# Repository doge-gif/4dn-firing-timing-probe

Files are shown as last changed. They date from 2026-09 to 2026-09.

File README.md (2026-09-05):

# 4dn-firing-timing-probe

A Raspberry Pi Pico (RP2040) bench instrument that maps the ignition **advance
curve (°BTDC vs RPM)** of a Denso TNDF17 TCI ignitor (as fitted to the Yamaha
SRV250, renessa). It emulates the crankshaft pickup at a commanded RPM,
timestamps the resulting ignition-coil fire events, and writes the per-cylinder
timing to CSV files on an onboard FAT volume, retrieved over USB mass storage.

No engine required: the Pico is both the stimulus (a synthesized pickup pattern)
and the instrument (dual-edge capture + crank-angle reconstruction).

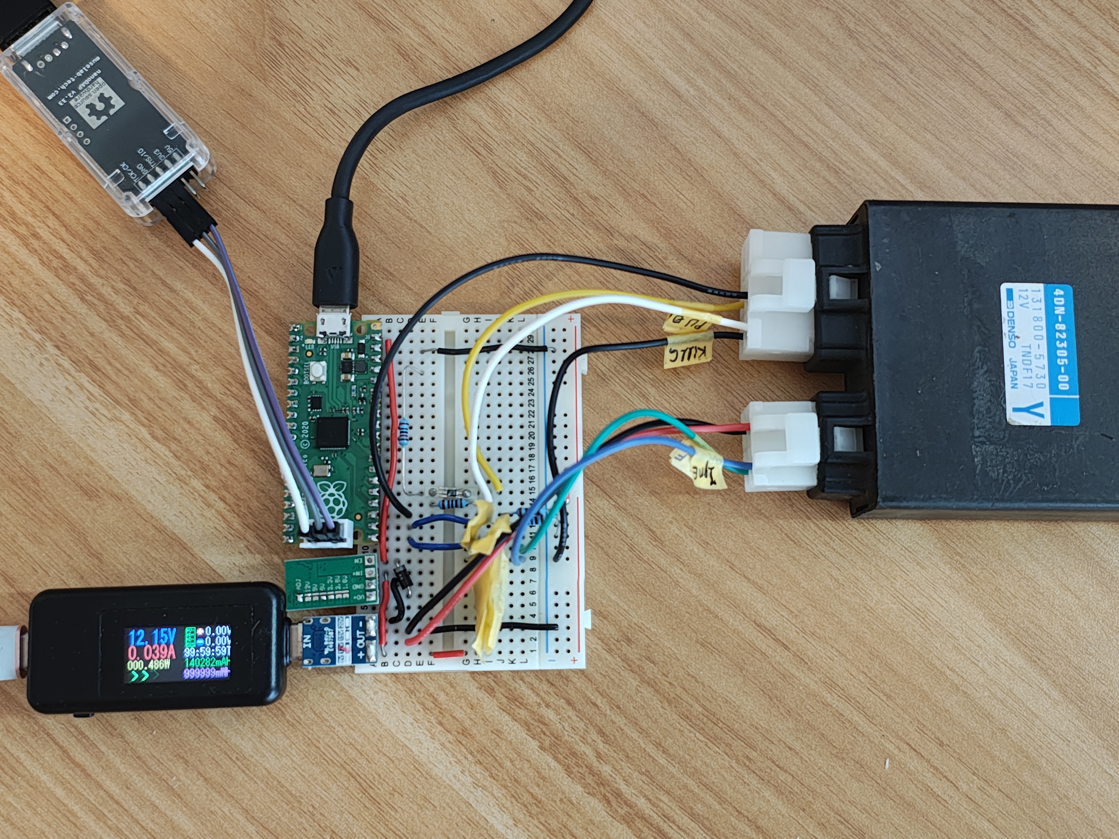
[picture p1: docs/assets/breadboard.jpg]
Breadboard prototype


> [!NOTE]
> This project is created with the help of AI. The schematic is made manually,
> but the firmware and documentation are generated with claude code.

## How it works

The Pico drives a synthesized VR/pickup pulse train on GP18 matching the SRV250
trigger wheel (4 teeth, 60/60/60/180°) at a commanded RPM. It captures both
edges of the ignitor's two coil outputs (GP16/GP17) and of its own emitted
pickup (GP18 self-capture) with the PIO on one shared 62.5 MHz timebase, then
computes each spark's °BTDC by interpolating its position between the bracketing
pickup edges relative to per-cylinder TDC. Details in
[docs/architecture.md](docs/architecture.md).

## Run modes & output

`RUN_MODE` in `CONFIG.INI` selects the run; results land as CSV on the USB drive:

| Mode | What it does | Output |
|---|---|---|
| `STEPPED` | Hold each RPM step, average N samples → advance map | `MAP_###.CSV` |
| `RAMP_UP` / `RAMP_DOWN` | Continuous RPM sweep, one row per spark | `RAMPU###.CSV` / `RAMPD###.CSV` |
| `HOLD` | Hold a constant RPM indefinitely, one row per spark | `HOLD###.CSV` |

## Quick start

1. **Flash the firmware.** Download the latest
   prober.uf2 from the project's GitHub [Releases][] page, then hold
   **BOOTSEL** while plugging in the Pico (it mounts as `RPI-RP2`) and copy the
   `.uf2` onto it. (Building from source instead:
   [docs/development.md](docs/development.md).)
2. **Wire the harness** to the ignitor — pin map in
   [docs/architecture.md](docs/architecture.md#hardware); board files and
   PCB/breadboard notes in [schematics/](schematics/README.md).
3. Mount the Pico's USB drive and edit `CONFIG.INI` — **run parameters only**;
   the wheel/TDC geometry is baked into the firmware.
4. **Reset** the Pico (config is read at boot), wait for the LED at 1 Hz
   (Ready), then press **BOOTSEL** to start the run.
5. Wait for the LED to return to steady **1 Hz (Ready)** — the run finished and
   the CSV is flushed — then replug the drive and copy the file. (Copying before
   the LED is Ready is too early; the file is written only at end-of-run.)

[Releases]: https://github.com/doge-gif/4dn-firing-timing-probe/releases/latest

## Repository layout

```
firmware/      C++20 firmware — core/ (SDK-free, host-tested), hal/, app/, tests/
schematics/    KiCad board + PCB/breadboard notes (schematics/README.md)
ci/            CI entry point (container build + lint + test)
docs/          architecture.md, development.md, refs/ (third-party sources)
results/       CSV output from my runs
flake.nix      Nix devShell (pinned toolchain: arm-none-eabi-gcc, probe-rs, …)
```

## License

Project source: see [LICENSE](LICENSE). Third-party reference materials indexed
in [docs/refs/SOURCES.md](docs/refs/SOURCES.md) remain under their own licenses.

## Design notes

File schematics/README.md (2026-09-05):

# 4DN Firing Timing Probe Schematics

This directory contains the schematics for the 4DN Firing Timing Probe.
See [releases][]: schematic.pdf for a PDF version.

The probe is simple enough that it'll work with a breadboard or protoboard. If
you want a proper PCB, use KiCad (10+) and send the gerbers to a fab house.

A gerber file for jlcpcb can be found in [releases][]: 4dn-firing-timing-probe-gerbers.zip.

[releases]: https://github.com/doge-gif/4dn-firing-timing-probe/releases/latest

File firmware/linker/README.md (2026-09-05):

# linker/

Link-time bound on the RAM-hot `.time_critical` code.

The `.time_critical` code is copied into the 264 KB SRAM at boot, so it is
capped at **12 KB** with a linker `ASSERT`: RAM-hot code that grows past the cap
is a BUILD FAILURE instead of silent RAM exhaustion at runtime.

## Files

- `prober_sections.ld` — extra `-T` fragment holding the top-level `ASSERT`
  (the 12 KB cap). Wired onto the `prober` target via `target_link_options` in
  `../src/CMakeLists.txt`.
- `section_default_data.incl` — override of the pico-sdk 2.3.0 file of the same
  name. Adds the `__time_critical_start__` / `__time_critical_end__` symbols
  that bracket `*(.time_critical*)`; the `ASSERT` asserts on their difference.
  Wired in via `pico_add_linker_script_override_path(prober ...)`.

## Why bracket symbols instead of `SIZEOF(.time_critical)`

In pico-sdk 2.x the `*(.time_critical*)` input sections are folded into the
`.data` output section (in SDK 1.x they were a standalone `.time_critical`
output section). So `SIZEOF(.time_critical)` is always 0 and a naive
`ASSERT(SIZEOF(.time_critical) <= 8K)` can never fire. Keeping the input inside
`.data` is also required for correctness: `crt0.S` copies
`[__data_start__, __data_end__)` from flash to SRAM at boot via a fixed copy
table, so relocating `.time_critical` into its own output section would leave
the hot functions uninitialised in RAM. Bracketing measures the code in place.

## Maintenance note

`section_default_data.incl` is a faithful copy of the vendored SDK file with
only the two bracket symbols added. If the vendored pico-sdk is bumped, re-sync
this override against the new `section_default_data.incl`.

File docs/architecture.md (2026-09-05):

# Architecture

How the prober turns a bare ignitor into an advance map, and how the firmware
and hardware are organised.

## Measurement principle

The SRV250 ignitor fires from a variable-reluctance crank pickup. The prober
*replaces the engine*: it synthesizes the pickup pulse train at a known,
commanded RPM and measures when the ignitor fires in response.

1. **Stimulus** — a CPU-timed pattern generator drives GP18 with the trigger
   wheel's edge sequence (4 teeth at 60/60/60/180°, each 10° wide) at the
   commanded RPM.
2. **Capture** — the PIO timestamps *both* edges of the two coil-drive outputs
   and of the emitted pickup itself, all against one free-running counter.
3. **Reconstruction** — each spark's crank angle is interpolated between the two
   pickup edges that bracket it; °BTDC = (TDC_ref − angle) mod wheel.

Because the pickup is emitted by the prober, the commanded RPM is exact and the
spark timing is measured, not assumed.

## Signal path and timebase

- **Pattern gen** (`hal/soft_pattern.hpp`): edges are emitted from a hardware
  timer-alarm IRQ, each edge time derived from the rev start plus a geometric
  fraction of the rev period — drift-free, and independent of main-loop load.
  RPM changes apply at the next rev boundary.
- **Capture** (`hal/capture.*`, `hal/capture.pio`): one PIO state machine per
  input pin does dual-edge timestamping into an SRAM ring via DMA, with the pin
  level packed into the timestamp so a dropped edge can't invert polarity. All
  SMs share clkdiv 1.0; the capture counter ticks at sysclk/2 = **62.5 MHz**
  (`kCaptureTicksPerCount = 2`). All capture SMs start in one synchronized batch, so
  they share a single phase-locked timebase.
- **Skew correction** (`core/skew.hpp`): each capture SM's counter pauses a
  fixed ~2.75 counts per edge it handles, so a fast channel (pickup, 8
  edges/rev) drifts against a slow one (a coil, ~2/rev). Each channel's
  accumulated pause is added back so all channels share one pause-free timebase
  — otherwise a spark compared to a tooth drifts over a run.

## BTDC computation

For each spark, `bracket_pk` finds the two emitted pickup edges `b`,`a` with
`b.t ≤ spark_t < a.t` and `interp_angle` interpolates the crank angle between
their known wheel angles. This is a **ratio within one revolution**, so the
capture counter's absolute rate cancels out — the result is robust to clock-rate
drift, and skew-corrected on top. `to_btdc` folds it against the cylinder's TDC.
The stepped and ramp/hold reducers share this exact math.

## Run modes

- **STEPPED** — the pattern runs continuously while the schedule steps RPM from
  `SWEEP_START_RPM` to `SWEEP_END_RPM` by `SWEEP_STEP_RPM`. At each step it lets
  the ignitor settle `SWEEP_SETTLE_REVS` revs, then averages `SWEEP_SAMPLES`
  sparks per cylinder (Welford mean/σ + median/min/max) into one row. An RPM
  with no fire is emitted as an `n=0` marker row (maps the cranking/redline
  edges). → `MAP_###.CSV`.
- **RAMP_UP / RAMP_DOWN** — RPM is integrated continuously by wall-clock time at
  `RAMP_UP_RPM_PER_S` / `RAMP_DOWN_RPM_PER_S` between the sweep bounds; every
  bracketable spark emits one raw row (no averaging). Hard-capped at 40 s.
  → `RAMPU###.CSV` / `RAMPD###.CSV`.
- **HOLD** — slews to `HOLD_RPM` and holds it indefinitely, one row per spark
  into a fixed most-recent-N window, until BOOTSEL is pressed. → `HOLD###.CSV`.

RAMP and HOLD share the per-spark reducer; STEPPED has its own averaging
reducer. All three share the pattern gen, capture, skew correction, and BTDC
math.

## Configuration model

Two tiers, deliberately split:

- **Baked geometry** (`firmware/src/constants.hpp`) — the DUT/wheel facts that
  are a property of the board, not an operator setting: `kWheelDeg`, the tooth
  spans, per-cylinder `kTdcRefDeg`, and the ignition-sense pins `kIgnPins`. The
  per-cylinder arrays are ordered in lockstep (cylinder *i* uses `kIgnPins[i]`
  and `kTdcRefDeg[i]`). Change these only for a different engine/board, then
  rebuild.
- **Run parameters** (`CONFIG.INI` on the USB volume) — `RUN_MODE`, the
  `SWEEP_*` scalars, optional `HOLD_RPM`, and the `RAMP_*_RPM_PER_S` rates. Read
  once at boot. A fresh device writes the baked default
  (`firmware/src/default_config.ini`, embedded via C23 `#embed`).

INI format: `key = value`; `;` starts a comment anywhere on a line; `:`
separates list items (e.g. per-cylinder values); keys are case-insensitive.

## Firmware structure

```
core/   Pure, SDK-free logic (INI parse, config validation, geometry, angle
        interpolation, skew, stats, CSV, FSM). Compiled for the host and unit-
        tested with doctest — no hardware needed.
hal/    RP2040 SDK layer: CPU pattern gen + PIO capture, DMA, GPIO, USB-MSC, flash
        FAT (FatFs). Isolated behind narrow interfaces.
app/    The application: dual-core wiring, run modes, the flush path.
```

**Dual-core split** (`app/`):

- **core0** (`main.cpp`) — USB (TinyUSB MSC), the tick-based FSM, and the
  end-of-run flush to flash. Owns all flash writes.
- **core1** (`core1_main.cpp`) — the deterministic domain: pattern emission,
  capture drain, per-spark reduction. Never touches flash during a run.

Rows cross core1→core0 over lock-free SPSC rings. Flash is written only at
end-of-run, while capture is idle and core1 is held in a RAM-resident lockout,
so an XIP flash program can't fault the other core.

**FSM states and LED** (`core/fsm.cpp`):

| State | LED | Meaning |
|---|-----|---|
| Ready | 1 Hz blink | idle; press BOOTSEL to start |
| Running | heartbeat | a run is in progress |
| Flush | double-blink | writing the CSV to flash |
| Done | brief solid | flush complete → returns to Ready |
| Error | triple-blink | lost sync (run aborted; no file written) |
| ConfigInvalid | 10 Hz blink | `CONFIG.INI` rejected at boot |

## Hardware

A Raspberry Pi Pico on a custom carrier PCB (KiCad project in
[`schematics/`](../schematics/README.md); it also runs on a breadboard).

The ignitor's internal output behaviour that the sense wiring and capture polarity
depend on — idle-high coil-drive outputs (12 V pull-up, pulled low during dwell) and
an open-collector tach — is derived from a
[reverse-engineered TNDF17 schematic](https://github.com/doge-gif/denso-TNDF17-reverse-engineer/blob/master/original_denso_TNDF17.pdf).

- **Power** — external 12 V (from a USB-C PD trigger negotiated by a CH221K)
  feeds the ignitor and an LM7805 12 V→5 V regulator; the 5 V drives Pico VSYS
  through a Schottky, source-OR'd with USB VBUS so the board runs standalone or
  over USB.
- **Pickup output** — GP18 → 100 Ω series resistor → the ignitor's pickup input;
  the 3V3 edge is enough to trigger its input stage.
- **Ignition sense (×2)** — each coil-drive line has a strong ≈470 Ω pull-up to
  +12 V, then a 2.7 kΩ / 1 kΩ divider scales the node down to just under 3.3 V at the
  MCU pin. Non-inverting, so the ignitor's collector polarity is preserved:
  idle-high, dwell-low, **spark = rising edge** — matching the firmware's idle-high
  capture.
- **Tach input (optional)** — GP19 via a low-Vf Schottky + 10 kΩ pull-up to 3V3;
  the ignitor's tach is an open-collector node, present only with a real ignitor.
- **Kill switch** — CONN_G pulled up; leave it open for run-enabled.

**Pin map:**

| GPIO | Signal | Notes |
|---|---|---|
| GP16 | Ignition sense, cylinder 2 | CONN_E |
| GP17 | Ignition sense, cylinder 1 | CONN_F |
| GP18 | Pickup output | SIO-driven; also PIO self-captured |
| GP19 | Tach input (optional) | reference diagnostic; absent on the bench |
| GP25 | Status LED | onboard |
| BOOTSEL | Start button | read via the QSPI-CS technique |

Note the cylinder↔connector mapping: CONN_E is cylinder 2 (GP16) and CONN_F is
cylinder 1 (GP17), so `kIgnPins = {17, 16}` (cyl0, cyl1).

## Output CSV formats

- **Stepped** (`MAP_###.CSV`):
  `rpm_cmd,cyl,n,mean_btdc_deg,median_btdc_deg,stddev_btdc_deg,min_btdc_deg,max_btdc_deg,mean_dwell_us,stddev_dwell_us,mean_sys_latency_us,tach_rpm`
- **Ramp / Hold** (`RAMPU###.CSV`, `RAMPD###.CSV`, `HOLD###.CSV`):
  `rpm_cmd,cyl,rev_period_us,btdc_deg,dwell_us`

Files are never overwritten — the firmware scans the volume for the lowest free
`###` on each flush.

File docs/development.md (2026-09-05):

# Development

Build, test, flash, and debug. Firmware structure and hardware are in
[architecture.md](architecture.md).

## Getting the source

The submodule dependencies are all top-level (`pico-sdk`, `doctest`, and
`tinyusb` — vendored directly rather than through pico-sdk's nested
`lib/tinyusb`, so no recursive fetch is needed). They are marked
`shallow = true`, so a single non-recursive init clones depth-1 snapshots only
(≈60 MB of `.git` instead of ≈470 MB); pico-sdk's unused nested libraries
(btstack, mbedtls, …) are never fetched. The checked-out files are identical.
(FatFs is not a submodule — it is vendored in-tree under `firmware/external/fatfs`
and needs no fetch; see [firmware/external/README.md](../firmware/external/README.md).)

```sh
git clone https://…/4dn-firing-timing-probe.git
# already cloned:
git submodule update --init
```

Two things when bumping the pico-sdk pin: re-pin `external/tinyusb` to the
tinyusb commit the new SDK expects (see `.gitmodules`), and fetch depth-matched
since shallow submodules lack other commits' history:
`git submodule update --remote --depth 1`.

## Toolchain

Everything runs inside one of two pinned environments — don't rely on host
tools:

- **Nix devShell** (local, recommended): `nix develop`. Provides
  `arm-none-eabi-gcc`, `cmake`, `probe-rs`, and the linters. Commands below
  assume you are inside it.
  Follow <https://nixos.org/download> to install Nix package manager.
- **Container** (what CI uses): `firmware/docker/run.sh bash -lc '…'`, built
  from the pinned image in `firmware/docker/`.

## Host unit tests

`core/` is SDK-free and tested with doctest on the host — no hardware:

```sh
cmake -S firmware -B build-host -DBUILD_TARGET=host
cmake --build build-host -j
ctest --test-dir build-host --output-on-failure
```

This is the default development path; run it before every commit.

## Firmware build

```sh
export PICO_SDK_PATH="$PWD/firmware/external/pico-sdk"
cmake -S firmware -B build-pico -DBUILD_TARGET=pico -DPICO_BOARD=pico
cmake --build build-pico --target prober -j
```

Outputs land in `build-pico/src/`: `prober.uf2` (for BOOTSEL/UF2) and
`prober.elf` (for probe-rs). Add `-DPROBER_HILTEST=ON` to also build the
on-silicon HIL self-test firmwares (`hil_ignitor`, `hil_ramp`, …); the normal
`prober` build does not need it.

## Flash

**UF2 (no probe):** hold BOOTSEL while plugging in the Pico → it mounts as
`RPI-RP2` → copy `build-pico/src/prober.uf2` onto it.

**SWD via probe-rs (CMSIS-DAP / DAPLINK):**

```sh
probe-rs download --chip RP2040 build-pico/src/prober.elf
probe-rs reset --chip RP2040
```

`download` reprograms only the firmware region — it does **not** touch the
top-of-flash FAT volume, so `CONFIG.INI` and result CSVs survive a reflash.

## Run and retrieve

1. Mount the Pico's USB drive; edit `CONFIG.INI` (run parameters only — see
   [architecture.md](architecture.md#configuration-model)).
2. **Reset** the Pico (config is read once at boot). LED patterns:

   | LED | State |
   |-----|-------|
   | 1 Hz blink | Ready — press BOOTSEL to start |
   | heartbeat | Running |
   | double-blink | Flushing the CSV |
   | brief solid | Done |
   | triple-blink | Error (lost sync; no file written) |
   | 10 Hz blink | Config invalid (fix `CONFIG.INI`) |

3. Press **BOOTSEL** to start. The volume is writer-locked read-only during a
   run.
4. **Wait for steady 1 Hz (Ready)** — the file is written only at end-of-run
   flush. Then replug the drive (the auto media-change is not reliable on all
   hosts) and copy the CSV.

## Debugging

- **SWD perturbs the pickup.** Poking RAM / halting over SWD during a *live
  run* garbles emission and measurement (and can even trip a USB panic). Read
  markers only when idle/Ready; for live signal checks use a scope on GP18 and
  the spark lines, not SWD.
- **Hung board:** `probe-rs gdb --chip RP2040 …` then attach `arm-none-eabi-gdb`
  (thread 1 = core0, thread 2 = core1) to read the fault PC / backtrace. Give
  the stub a few seconds to come up.
- **Corrupt FS recovery:** zero the FAT boot sector to force a reformat on next
  boot (the device rewrites a default `CONFIG.INI`):

  ```sh
  head -c 4096 /dev/zero > zero4k.bin
  probe-rs download --chip RP2040 --binary-format bin --base-address 0x10180000 zero4k.bin
  probe-rs reset --chip RP2040
  ```

  (`probe-rs erase` full-chip is unreliable on the DAPLINK; zeroing the boot
  sector is the working path.)

## Full CI locally

Build + lint (rumdl/shfmt/shellcheck/hadolint) + host & pico builds +
clang-format + clang-tidy, exactly as CI runs it:

```sh
firmware/docker/run.sh bash -lc '../ci/run.sh'
```

## Commit hooks

`lefthook` runs `clang-format`, `gersemi`, `rumdl`, `shfmt`, and `shellcheck` on
commit — **commit from inside `nix develop`** so the hooks are on PATH.
`clang-format` frequently reformats and fails the first attempt; the reliable
pattern is `clang-format -i <files>` → `git add` → `git commit`.

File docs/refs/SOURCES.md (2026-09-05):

# Reference Sources

Third-party documents mirrored in this directory for offline development.
Each file is covered by its original author's license.

| File | Origin URL | Retrieved | License |
|---|---|---|---|
| rp2040-datasheet.pdf | https://datasheets.raspberrypi.com/rp2040/rp2040-datasheet.pdf | 2026-09-04 | © Raspberry Pi Ltd |
| pico-datasheet.pdf | https://datasheets.raspberrypi.com/pico/pico-datasheet.pdf | 2026-09-04 | © Raspberry Pi Ltd |
| hardware-design-with-rp2040.pdf | https://datasheets.raspberrypi.com/rp2040/hardware-design-with-rp2040.pdf | 2026-09-04 | © Raspberry Pi Ltd |
| raspberry-pi-pico-c-sdk.pdf | https://datasheets.raspberrypi.com/pico/raspberry-pi-pico-c-sdk.pdf | 2026-09-04 | BSD-3-Clause |
| getting-started-with-pico.pdf | https://datasheets.raspberrypi.com/pico/getting-started-with-pico.pdf | 2026-09-04 | © Raspberry Pi Ltd |

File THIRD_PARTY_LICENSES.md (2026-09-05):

# Third-Party Licenses

<!-- GENERATED FILE — do not edit by hand.
     Regenerate with: scripts/gen-third-party-licenses.sh
     Source of truth: THIRD_PARTY_MANIFEST.tsv -->

This project bundles the third-party components below. Each is distributed under
its own license, reproduced verbatim here. Ship this file alongside the firmware
binary (prober.uf2) to satisfy those licenses' attribution requirements.

## Components in the firmware binary (prober.uf2)

### Raspberry Pi Pico SDK — BSD-3-Clause

```text
Copyright 2020 (c) 2020 Raspberry Pi (Trading) Ltd.

Redistribution and use in source and binary forms, with or without modification, are permitted provided that the
following conditions are met:

1. Redistributions of source code must retain the above copyright notice, this list of conditions and the following
   disclaimer.

2. Redistributions in binary form must reproduce the above copyright notice, this list of conditions and the following
   disclaimer in the documentation and/or other materials provided with the distribution.

3. Neither the name of the copyright holder nor the names of its contributors may be used to endorse or promote products
   derived from this software without specific prior written permission.

THIS SOFTWARE IS PROVIDED BY THE COPYRIGHT HOLDERS AND CONTRIBUTORS "AS IS" AND ANY EXPRESS OR IMPLIED WARRANTIES,
INCLUDING, BUT NOT LIMITED TO, THE IMPLIED WARRANTIES OF MERCHANTABILITY AND FITNESS FOR A PARTICULAR PURPOSE ARE
DISCLAIMED. IN NO EVENT SHALL THE COPYRIGHT HOLDER OR CONTRIBUTORS BE LIABLE FOR ANY DIRECT, INDIRECT, INCIDENTAL,
SPECIAL, EXEMPLARY, OR CONSEQUENTIAL DAMAGES (INCLUDING, BUT NOT LIMITED TO, PROCUREMENT OF SUBSTITUTE GOODS OR
SERVICES; LOSS OF USE, DATA, OR PROFITS; OR BUSINESS INTERRUPTION) HOWEVER CAUSED AND ON ANY THEORY OF LIABILITY,
WHETHER IN CONTRACT, STRICT LIABILITY, OR TORT (INCLUDING NEGLIGENCE OR OTHERWISE) ARISING IN ANY WAY OUT OF THE USE OF
THIS SOFTWARE, EVEN IF ADVISED OF THE POSSIBILITY OF SUCH DAMAGE.
```

### TinyUSB — MIT

```text
The MIT License (MIT)

Copyright (c) 2018, hathach (tinyusb.org)

Permission is hereby granted, free of charge, to any person obtaining a copy
of this software and associated documentation files (the "Software"), to deal
in the Software without restriction, including without limitation the rights
to use, copy, modify, merge, publish, distribute, sublicense, and/or sell
copies of the Software, and to permit persons to whom the Software is
furnished to do so, subject to the following conditions:

The above copyright notice and this permission notice shall be included in
all copies or substantial portions of the Software.

THE SOFTWARE IS PROVIDED "AS IS", WITHOUT WARRANTY OF ANY KIND, EXPRESS OR
IMPLIED, INCLUDING BUT NOT LIMITED TO THE WARRANTIES OF MERCHANTABILITY,
FITNESS FOR A PARTICULAR PURPOSE AND NONINFRINGEMENT. IN NO EVENT SHALL THE
AUTHORS OR COPYRIGHT HOLDERS BE LIABLE FOR ANY CLAIM, DAMAGES OR OTHER
LIABILITY, WHETHER IN AN ACTION OF CONTRACT, TORT OR OTHERWISE, ARISING FROM,
OUT OF OR IN CONNECTION WITH THE SOFTWARE OR THE USE OR OTHER DEALINGS IN
THE SOFTWARE.
```

### FatFs (ELM ChaN) — BSD-1-Clause

**Provenance:** Vendored from http://elm-chan.org/fsw/ff/ (R0.15a, retrieved 2026-09-02)

```text
FatFs License

FatFs has being developped as a personal project of the author, ChaN. It is free from the code anyone else wrote at current release. Following code block shows a copy of the FatFs license document that heading the source files.

/*----------------------------------------------------------------------------/
/  FatFs - Generic FAT Filesystem Module  Rx.xx                               /
/-----------------------------------------------------------------------------/
/
/ Copyright (C) 20xx, ChaN, all right reserved.
/
/ FatFs module is an open source software. Redistribution and use of FatFs in
/ source and binary forms, with or without modification, are permitted provided
/ that the following condition is met:
/
/ 1. Redistributions of source code must retain the above copyright notice,
/    this condition and the following disclaimer.
/
/ This software is provided by the copyright holder and contributors "AS IS"
/ and any warranties related to this software are DISCLAIMED.
/ The copyright owner or contributors be NOT LIABLE for any damages caused
/ by use of this software.
/----------------------------------------------------------------------------*/

Therefore FatFs license is one of the BSD-style licenses, but there is a significant feature. FatFs is mainly intended for embedded systems. In order to extend the usability for commercial products, the redistributions of FatFs in binary form, such as embedded code, binary library and any forms without source code, do not need to include about FatFs in the documentations. This is equivalent to the 1-clause BSD license. Of course FatFs is compatible with the most of open source software licenses include GNU GPL. When you redistribute the FatFs source code with changes or create a fork, the license can also be changed to GNU GPL, BSD-style license or any open source software license that not conflict with FatFs license.
```

## Components used only for host tests (not in prober.uf2)

The following are build/test dependencies only. They are not linked into the
distributed firmware, and are listed here for completeness.

### doctest — MIT

```text
The MIT License (MIT)

Copyright (c) 2016-2023 Viktor Kirilov

Permission is hereby granted, free of charge, to any person obtaining a copy
of this software and associated documentation files (the "Software"), to deal
in the Software without restriction, including without limitation the rights
to use, copy, modify, merge, publish, distribute, sublicense, and/or sell
copies of the Software, and to permit persons to whom the Software is
furnished to do so, subject to the following conditions:

The above copyright notice and this permission notice shall be included in all
copies or substantial portions of the Software.

THE SOFTWARE IS PROVIDED "AS IS", WITHOUT WARRANTY OF ANY KIND, EXPRESS OR
IMPLIED, INCLUDING BUT NOT LIMITED TO THE WARRANTIES OF MERCHANTABILITY,
FITNESS FOR A PARTICULAR PURPOSE AND NONINFRINGEMENT. IN NO EVENT SHALL THE
AUTHORS OR COPYRIGHT HOLDERS BE LIABLE FOR ANY CLAIM, DAMAGES OR OTHER
LIABILITY, WHETHER IN AN ACTION OF CONTRACT, TORT OR OTHERWISE, ARISING FROM,
OUT OF OR IN CONNECTION WITH THE SOFTWARE OR THE USE OR OTHER DEALINGS IN THE
SOFTWARE.
```

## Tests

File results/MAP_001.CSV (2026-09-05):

# firmware: v1.0.1
rpm_cmd | cyl | n | mean_btdc_deg | median_btdc_deg | stddev_btdc_deg | min_btdc_deg | max_btdc_deg | mean_dwell_us | stddev_dwell_us | mean_sys_latency_us | tach_rpm
100 | 0 | 16 | 9.83 | 9.83 | 0.00 | 9.83 | 9.83 | 100145.05 | 1.10 | 200.02 | 100.00
100 | 1 | 16 | 9.83 | 9.83 | 0.00 | 9.83 | 9.83 | 100135.58 | 0.81 | 200.02 | 100.00
200 | 0 | 16 | 9.66 | 9.66 | 0.00 | 9.65 | 9.66 | 50145.00 | 1.91 | 200.27 | 191.30
200 | 1 | 16 | 9.67 | 9.67 | 0.00 | 9.66 | 9.67 | 50136.07 | 2.50 | 200.27 | 191.30
300 | 0 | 16 | 9.48 | 9.48 | 0.00 | 9.47 | 9.49 | 33479.22 | 5.93 | 200.06 | 293.33
300 | 1 | 16 | 9.50 | 9.50 | 0.00 | 9.50 | 9.50 | 33466.81 | 2.44 | 200.06 | 293.33
400 | 0 | 16 | 9.32 | 9.33 | 0.00 | 9.31 | 9.33 | 25144.87 | 3.27 | 200.20 | 394.03
400 | 1 | 16 | 9.35 | 9.35 | 0.00 | 9.34 | 9.35 | 25135.20 | 2.53 | 200.20 | 394.03
500 | 0 | 16 | 9.16 | 9.16 | 0.01 | 9.13 | 9.16 | 20145.49 | 2.03 | 200.26 | 494.38
500 | 1 | 16 | 9.18 | 9.18 | 0.01 | 9.17 | 9.19 | 20135.32 | 3.26 | 200.26 | 494.38
600 | 0 | 16 | 8.99 | 8.99 | 0.00 | 8.98 | 8.99 | 16810.36 | 1.58 | 200.10 | 594.59
600 | 1 | 16 | 9.02 | 9.02 | 0.00 | 9.01 | 9.02 | 16802.99 | 1.15 | 200.10 | 594.59
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

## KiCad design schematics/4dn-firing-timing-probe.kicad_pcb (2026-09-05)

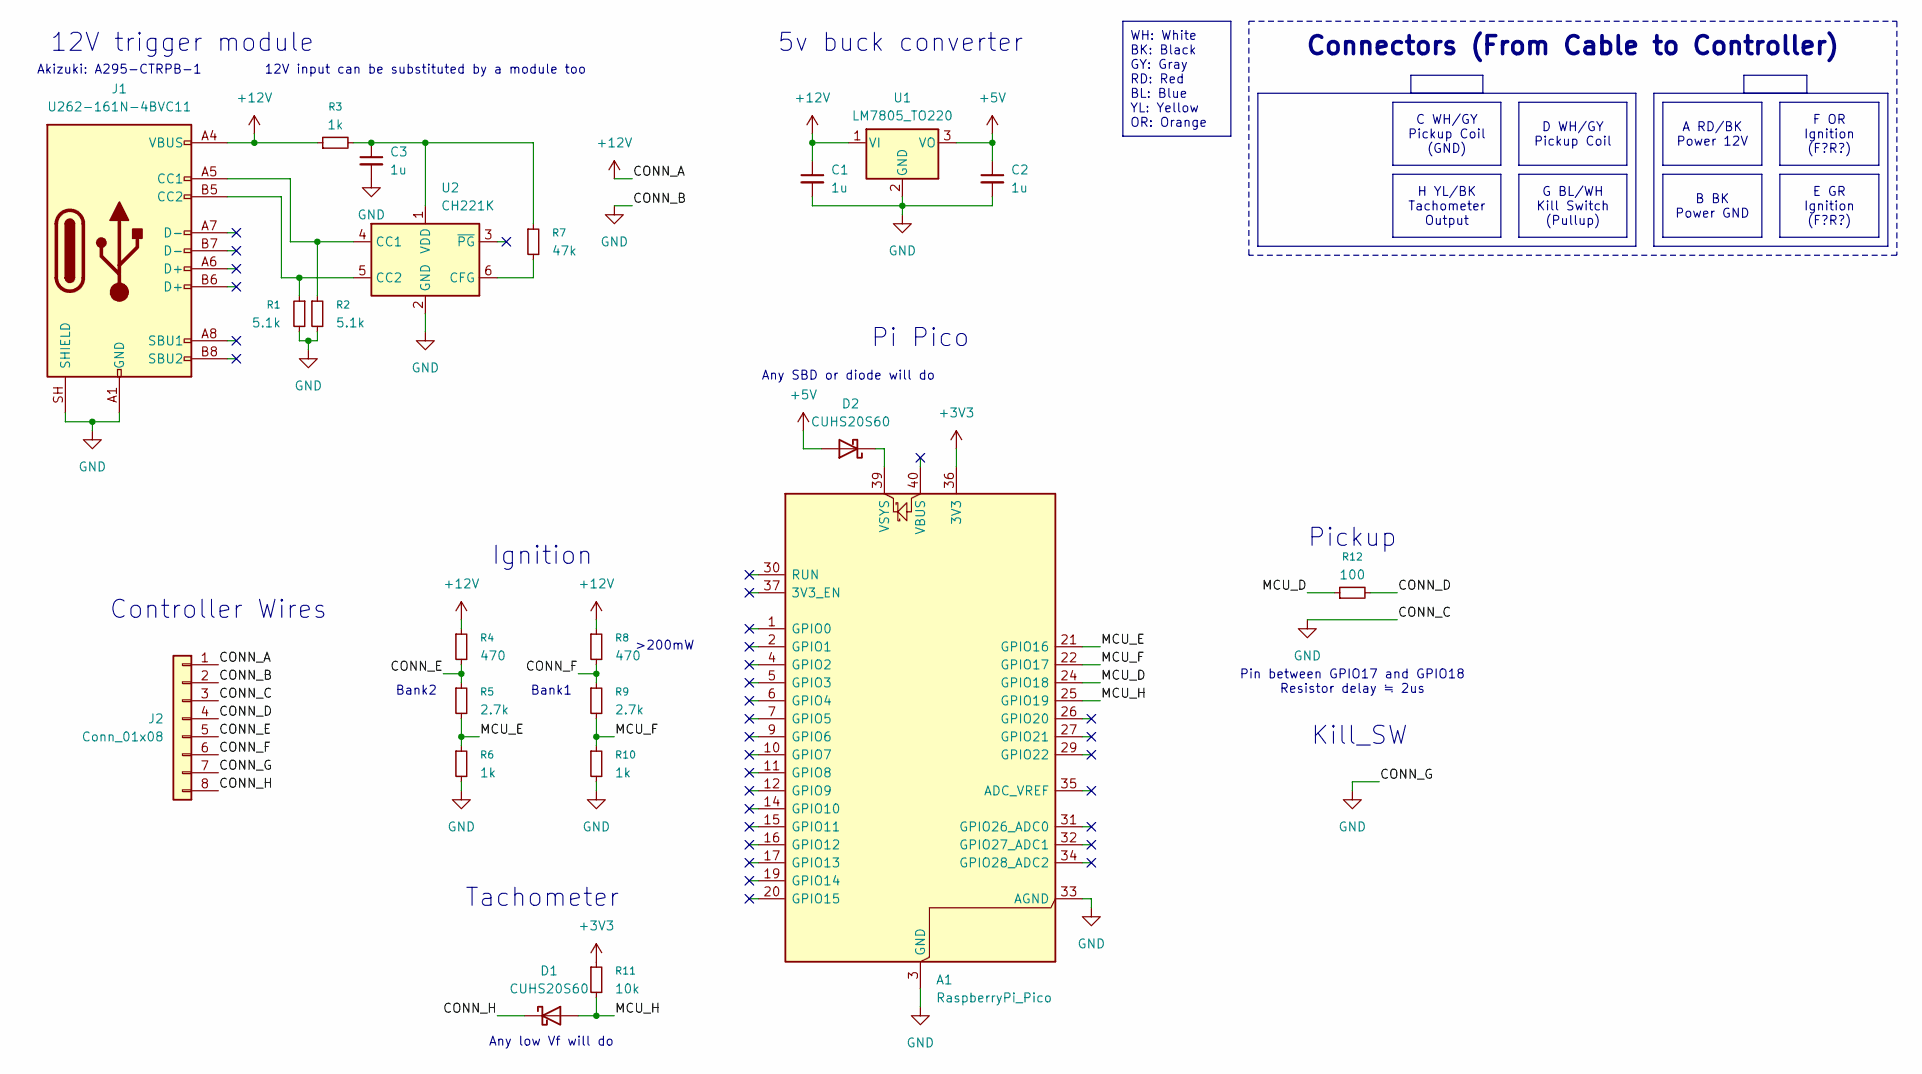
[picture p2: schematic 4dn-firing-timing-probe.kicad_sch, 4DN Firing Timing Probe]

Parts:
A1: RaspberryPi_Pico; RaspberryPi_Pico_Common_SMD
C1, C2, C3: 1u; C_0603_1608Metric
D1, D2: CUHS20S60; D_TUMD2
J1: U262-161N-4BVC11; USB_C_Receptacle_Palconn_UTC16-G
J2: Conn_01x08; PinHeader_1x08_P2.54mm_Vertical
R1, R2: 5.1k; R_0603_1608Metric
R3, R6, R10: 1k; R_0603_1608Metric
R4, R8: 470; R_1206_3216Metric
R5, R9: 2.7k; R_0603_1608Metric
R7: 47k; R_0603_1608Metric
R11: 10k; R_0603_1608Metric
R12: 100; R_0603_1608Metric
U1: LM7805_TO220; TO-220-3_Vertical
U2: CH221K; SOT-23-6

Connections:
+3V3: A1.36 (3V3), R11.1
+5V: C2.1, D2.2 (A), U1.3 (VO)
+12V: C1.1, J1.A4 (VBUS), J1.A9 (VBUS), J1.B4 (VBUS), J1.B9 (VBUS), J2.1, R3.1, R4.1, R8.1, U1.1 (VI)
/CONN_D: J2.4, R12.2
/CONN_E: J2.5, R4.2, R5.1
/CONN_F: J2.6, R8.2, R9.1
/CONN_H: D1.1 (K), J2.8
/MCU_D: A1.24 (GPIO18), R12.1
/MCU_E: A1.21 (GPIO16), R5.2, R6.1
/MCU_F: A1.22 (GPIO17), R9.2, R10.1
/MCU_H: A1.25 (GPIO19), D1.2 (A), R11.2
GND: A1.3 (GND), A1.8 (GND), A1.13 (GND), A1.18 (GND), A1.23 (GND), A1.28 (GND), A1.33 (AGND), A1.38 (GND), C1.2, C2.2, C3.2, J1.A1 (GND), J1.A12 (GND), J1.B1 (GND), J1.B12 (GND), J1.SH (SHIELD), J2.2, J2.3, J2.7, R1.2, R2.2, R6.2, R10.2, U1.2 (GND), U2.2 (GND)
unnamed: A1.39 (VSYS), D2.1 (K)
unnamed: J1.A5 (CC1), R2.1, U2.4 (CC1)
unnamed: J1.B5 (CC2), R1.1, U2.5 (CC2)
unnamed: R7.2, U2.6 (CFG)
unnamed: C3.1, R3.2, R7.1, U2.1 (VDD)

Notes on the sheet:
Bank2
Ignition
Tachometer
Akizuki: A295-CTRPB-1
Controller Wires
Pi Pico
Any low Vf will do
Any SBD or diode will do
Pickup
5v buck converter
Kill_SW
>200mW
Bank1
12V input can be substituted by a module too
12V trigger module
Pin between GPIO17 and GPIO18 Resistor delay ≒ 2us
A RD/BK Power 12V
G BL/WH Kill Switch (Pullup)
C WH/GY Pickup Coil (GND)
E GR Ignition (F?R?)
Connectors (From Cable to Controller)
B BK Power GND
D WH/GY Pickup Coil
WH: White BK: Black GY: Gray RD: Red BL: Blue YL: Yellow OR: Orange
F OR Ignition (F?R?)
H YL/BK Tachometer Output

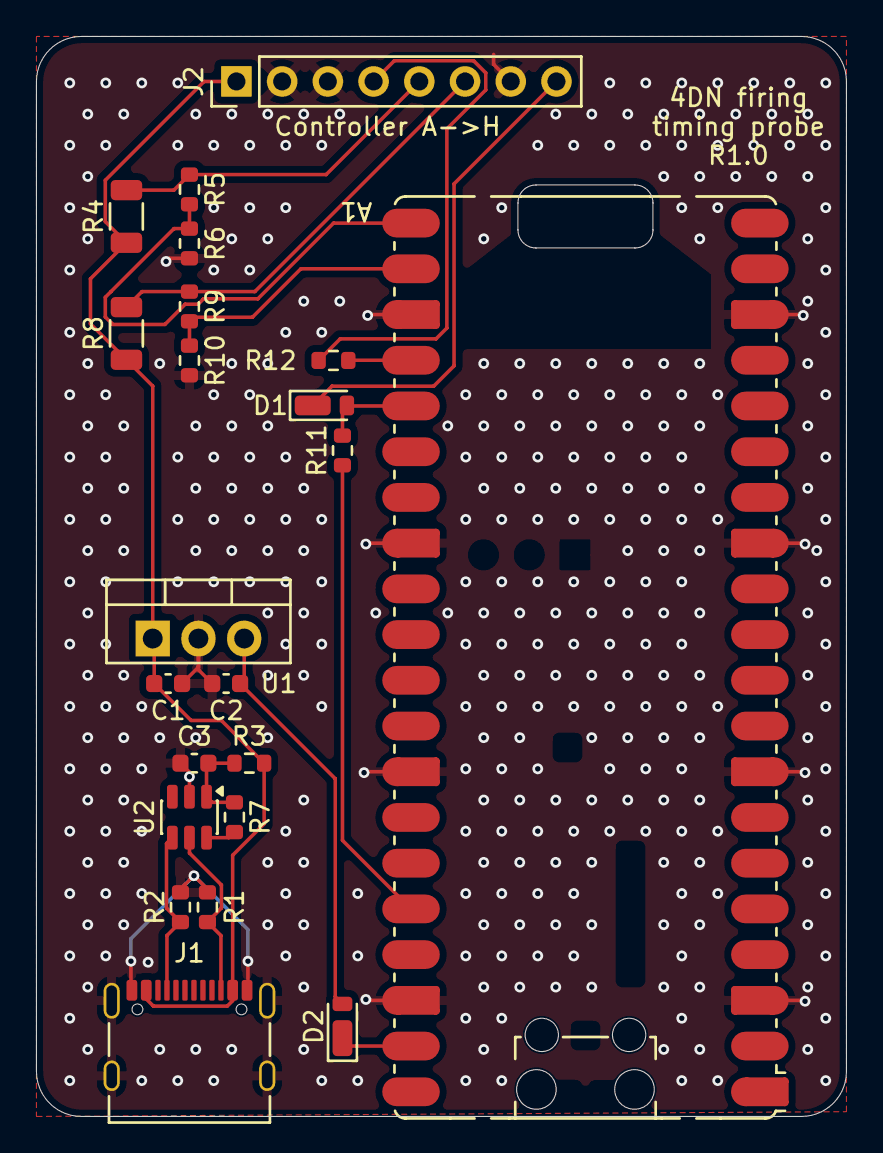
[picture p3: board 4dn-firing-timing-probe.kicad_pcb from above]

Board: 2 copper layers, 45.0 x 60.0 mm, 22 parts (0 on the bottom side), 17 nets.

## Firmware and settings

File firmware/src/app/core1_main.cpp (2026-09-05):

#include "app/core1_main.hpp"

#include "app/run_modes.hpp"
#include "core/angle.hpp"
#include "core/config.hpp"
#include "core/csv.hpp"
#include "core/skew.hpp"
#include "core/stats.hpp"
#include "core/tach.hpp"
#include "core/types.hpp"
#include "hal/capture.hpp"
#include "hal/gpio.hpp"
#include "hal/pins.hpp"
#include "hal/soft_pattern.hpp"
#include "hardware/pio.h"
#include "pico/multicore.h"
#include "pico/stdlib.h"

#include <cmath>
#include <cstddef>
#include <cstdint>

// This is the deterministic domain. It mirrors the SAME reduction that the
// single-core self-test (firmware/hiltest/selftest.cpp) proved -- per RPM step
// reconfigure the pickup pattern, capture edges, bracket a spark time between
// captured pickup edges, interp_angle -> to_btdc -> Welford + median/min/max ->
// SteppedRow -- except the sparks now come from the real ignition-sense capture
// channels (GP16/GP17) instead of a synthetic time delay, and the reduced rows
// are pushed to core0 over the SPSC ring instead of printed.
//
// The pure reduction math here is host-unit-tested. The real-ignition spark path
// (bracketing captured ignition RISING edges against captured pickup edges,
// per-cylinder) can only be exercised on hardware with a real ignitor + wiring
// loom connected -- on the bench there are no ignition-sense edges, so that path
// is written to be structurally correct and heavily commented, and yields an
// empty (no-fire) reduction.

namespace app {

// The single shared core0<->core1 state block (declared extern in the header).
Intercore g_ic;

namespace {

// ---- Fixed hardware assignment ---------------------------------------------
// SoftPattern: core1 CPU bit-bang (GP18 as SIO output)              -> drives GP18
// Capture    : pio1 sm0/sm1/sm2/sm3    (+1 DMA each)                 -> reads pins
//   slot 0 = pickup self-capture GP18 (idle-LOW,  first edge RISING)
//   slot 1 = ignition sense    GP17 (idle-HIGH, first edge FALLING) -> cyl 0
//   slot 2 = ignition sense    GP16 (idle-HIGH, first edge FALLING) -> cyl 1
//   slot 3 = tach diagnostic   GP19 (idle-HIGH, first edge FALLING) -> reference
// Budget: pio0 entirely FREE (pattern gen moved to CPU); pio1 uses 4 SMs (FULL).
// DMA: 0 + 4 = 4 (of 12). The pickup pad is SIO-driven and pio1 reads its input
// synchronizer, so self-capture is unaffected (capture_program_init never calls
// pio_gpio_init). More capture channels could now reclaim any pio0 SM.
constexpr std::size_t kSlotPickup = 0;
constexpr std::size_t kSlotIgn0 = 1;
constexpr std::size_t kSlotIgn1 = 2;
constexpr std::size_t kSlotTach = 3;

// CaptureEvent.ch id for the pickup channel. Ignition channels are stamped with
// the cylinder index (0/1) so DwellPairer and cfg.tdc_ref_deg[] index directly;
// the pickup channel needs an id that never collides with a cylinder index.
constexpr std::uint8_t kPickupChId = 0xFF;
// CaptureEvent.ch id for the tach reference-diagnostic channel. Distinct from the
// pickup (0xFF) and cylinder indices (0/1) so routing never collides.
constexpr std::uint8_t kTachChannel = 0xFE;

// Capture counter is sysclk/2 = 62.5 MHz (see hal::kCaptureTicksPerCount), so a
// DELTA of two `ticks` in microseconds = delta / 62.5. Used only for dwell (the
// angle math needs no absolute rate -- interp_angle works in raw ticks).
constexpr float kCaptureCountsPerUs = cfg::kCaptureCountsPerUs;

// Rolling pickup-edge history depth. Sparks are almost always bracketable within
// the same drain() (pickup events are drained before ign events, so the history
// already covers the drain instant); this ring only needs to outlive a spark
// whose trailing pickup edge lands in the NEXT drain, plus the settle margin.
constexpr std::size_t kPkRingCap = 64;

// Per-cylinder caps for one step.
constexpr std::size_t kMaxSamples = 64;      // BTDC/dwell samples reduced per step
constexpr std::size_t kMaxPending = 8;       // sparks awaiting their trailing pickup edge
constexpr std::size_t kEventsPerDrain = 192; // CaptureEvent scratch per drain() call

// Fast "no fire at this rpm" detection (range scan): if NO spark has
// appeared within settle + this many revs, the ignitor is not firing at this rpm
// (below cranking / past redline). We record an empty row and move on rather than
// burning the full sample timeout -- important at low rpm where one rev is long.
constexpr std::uint32_t kNoFireMarginRevs = 6;

// Hard wall-time cap on a ramp run so a stall / non-terminating schedule can never
// hang core1 (self-recovering HIL-gate rule; see run_ramp). Generous vs a normal
// full-range ramp (~20 s at 500 rpm/s).
constexpr std::uint64_t kRampWallCapUs = 40'000'000; // 40 s

// One captured pickup edge: its time, its intra-rev wheel angle (kept SMALL, in
// [0,wheel)), and an integer rev index. bracket_pk reconstructs the monotonic
// spark angle in a b-relative frame from (intra, rev) so a long sweep's large rev
// count never costs float precision; to_btdc folds the result into [0,wheel). rev
// stays an exact integer (used for the settle window and the rev-boundary wrap).
struct PkEdge {
  std::uint64_t t = 0;
  float intra = 0.0f; // intra-rev wheel angle [0, wheel)
  std::uint32_t rev = 0;
};

// A spark (ignition RISING edge) awaiting bracketing pickup edges. dwell is the
// charge duration paired by DwellPairer at the spark instant (fall->rise).
struct PendingSpark {
  std::uint64_t t = 0;
  bool has_dwell = false;
  std::uint64_t dwell_ticks = 0;
};

// Per-step accumulator + reducer for one full RPM step. Not persisted across
// steps (constructed fresh each step) except through the pipeline's own fields.
struct Reducer {
  // Pickup history ring (see kPkRingCap). pk_total_ counts ALL pickup edges seen
  // this step; the valid window is the last min(pk_total_, kPkRingCap) entries.
  PkEdge pk_[kPkRingCap]{};
  std::uint32_t pk_total_ = 0;

  // Per-cylinder reduction state.
  core::Welford btdc_[core::kMaxCylinders]{};
  core::Welford dwell_[core::kMaxCylinders]{};
  float btdc_buf_[core::kMaxCylinders][kMaxSamples]{};
  std::uint32_t got_[core::kMaxCylinders]{};

  // Per-cylinder pending sparks (small; drained each pass).
  PendingSpark pend_[core::kMaxCylinders][kMaxPending]{};
  std::size_t npend_[core::kMaxCylinders]{};

  // One DwellPairer instance covers all cylinders (state is per ch internally).
  core::DwellPairer pairer_{};

  // ---- Tach REFERENCE diagnostics (system input latency + sync-lock RPM).
  // REFERENCE only -- never used to correct BTDC. On the bench there is no tach
  // signal (it exists only with the real ignitor), so no tach edges arrive and
  // these stay empty -> the row fields default to 0. This path is exercised only
  // with a real ignitor connected. See process_tach_edge below for the
  // edge-matching logic.
  std::uint64_t last_tooth0_t_ = 0; // last emitted tooth-0 RISING edge (from pickup)
  bool have_tooth0_ = false;
  core::TachDiag tach_{}; // per-step sync-lock RPM + input-latency accumulator

  // Geometry cache for this step.
  float intra_angle_[core::kMaxTeeth * 2]{}; // wheel angle of each edge in a rev
  std::size_t edges_per_rev_ = 0;
  float wheel_deg_ = 360.0f;
  std::uint32_t settle_revs_ = 0;
  std::uint32_t step_rev0_ = 0; // sync-rev index at the current step's entry
  std::uint32_t want_ = 0;
  std::uint32_t rpm_cmd_ = 0; // commanded rpm for this step (stamped into each row)
  std::uint8_t cyl_count_ = 1;
  const core::Config* cfg_ = nullptr;

  // Sync-gap tooth-0 alignment (self-healing; config-derived threshold). The
  // largest inter-edge gap is the sync gap; crossing it re-aligns intra_idx_ to 0
  // and bumps sync_rev_ every revolution, so a spurious startup edge or any single
  // miscount corrupts at most one rev instead of shifting the whole map. Replaces
  // the fragile "first captured edge == tooth-0, index == pk_total_" assumption
  // (which the raw capture proved wrong -- pk[0] is a spurious startup edge).
  std::uint64_t last_pk_t_ = 0;
  bool have_last_pk_ = false;
  float sync_thresh_deg_ = 0.0f;        // from cfg (build_intra_table)
  std::uint64_t sync_thresh_ticks_ = 0; // sync_thresh_deg_ scaled to this step's rpm
  std::size_t intra_idx_ = 0;           // edge index within the current rev
  std::uint32_t sync_rev_ = 0;          // revs since the first sync gap
  bool synced_ = false;                 // a sync gap has been seen -> angles valid

  // Per-channel capture-clock skew correction. Each capture SM's counter PAUSES
  // ~2.75 counts while handling an edge (mov/in/in/push don't decrement it), so a
  // channel's timestamps fall behind real time by k_cpe_ * (edges it has handled).
  // The pickup (8 edges/rev) drifts far faster than an ignition line (~2/rev), so
  // a spark's time vs a tooth's time -- compared ACROSS the two counters -- gains a
  // growing error over a run (the ATDC drift we chased). Fix: add each channel's
  // accumulated pause back, putting all channels on one pause-free timebase.
  // Per-channel edge counts feed the fixed-K correction (cfg::kCounterPauseCountsPerEdge).
  // ch idx: 0 pickup, 1 cyl0, 2 cyl1, 3 tach.
  std::uint64_t ch_edges_[4]{};
};

// Map a CaptureEvent.ch id to a ch_edges_ index (0 pickup, 1 cyl0, 2 cyl1, 3 tach),
// or -1 if it is not a corrected channel.
inline int skew_ch_idx(std::uint8_t ch) {
  if (ch == kPickupChId)
    return 0;
  if (ch == kTachChannel)
    return 3;
  if (ch < 2)
    return static_cast<int>(ch) + 1;
  return -1;
}

// Config-derived sync-gap threshold (degrees). The pickup's largest inter-EDGE
// angular gap is the sync gap (SRV250: 170 deg, tooth-3 trailing -> tooth-0
// leading); the largest NON-sync gap is the widest inter-tooth gap (50 deg). Any
// gap wider than the midpoint of those two is unambiguously the sync gap. Derived
// purely from cfg.teeth -- nothing hardcoded. 0 if geometry is degenerate (which
// disables sync detection -> the pipeline simply never brackets, never lies).
float sync_thresh_deg_from_cfg(const core::Config& cfg) {
  std::size_t tc = cfg.tooth_count > core::kMaxTeeth ? core::kMaxTeeth : cfg.tooth_count;
  if (tc < 2)
    return 0.0f;
  const float wheel = cfg.wheel_deg > 0.0f ? cfg.wheel_deg : 360.0f;
  float edges[core::kMaxTeeth * 2];
  std::size_t n = 0;
  for (std::size_t i = 0; i < tc; ++i) {
    edges[n++] = cfg.teeth[i].leading_deg;
    edges[n++] = cfg.teeth[i].trailing_deg;
  }
  float largest = 0.0f, second = 0.0f;
  for (std::size_t i = 0; i < n; ++i) {
    const float g = (i + 1 < n) ? (edges[i + 1] - edges[i]) : (edges[0] + wheel - edges[i]);
    if (g > largest) {
      second = largest;
      largest = g;
    } else if (g > second) {
      second = g;
    }
  }
  return 0.5f * (largest + second);
}

// Convert a sync-gap threshold in wheel-degrees to capture-count ticks at `rpm`.
// Gaps scale with rpm; the threshold tracks so detection is rpm-independent in
// effect. Lenient by construction (midpoint of the two largest gaps), so it stays
// correct even if the actual rpm drifts from commanded within a rev. sync_deg and
// wheel_deg are both wheel-frame degrees; the proper fix is a strong Deg units type
// threaded through the angle math (deferred as a larger change), so a swap is for now
// guarded only by the named call site.
// NOLINTNEXTLINE(bugprone-easily-swappable-parameters)
std::uint64_t sync_thresh_ticks(float sync_deg, float wheel_deg, std::uint32_t rpm) {
  if (sync_deg <= 0.0f || rpm == 0)
    return 0;
  const double rev_ticks = (60.0e6 / double(rpm)) * double(kCaptureCountsPerUs);
  const double wheel = wheel_deg > 0.0f ? double(wheel_deg) : 360.0;
  return static_cast<std::uint64_t>(double(sync_deg) / wheel * rev_ticks);
}

// Flatten the config's tooth spans into the per-edge intra-revolution angle table
// (leading = rising, trailing = falling), the same order the pickup emits edges.
void build_intra_table(Reducer& rd, const core::Config& cfg) {
  rd.cfg_ = &cfg;
  rd.wheel_deg_ = cfg.wheel_deg;
  rd.cyl_count_ = cfg.cyl_count ? cfg.cyl_count : 1;
  std::size_t tc = cfg.tooth_count;
  if (tc > core::kMaxTeeth)
    tc = core::kMaxTeeth;
  std::size_t n = 0;
  for (std::size_t i = 0; i < tc; ++i) {
    rd.intra_angle_[n++] = cfg.teeth[i].leading_deg;
    rd.intra_angle_[n++] = cfg.teeth[i].trailing_deg;
  }
  rd.edges_per_rev_ = n;
  rd.sync_thresh_deg_ = sync_thresh_deg_from_cfg(cfg); // per-rpm ticks set in run_step
}

// Find the bracketing pair (before,after) around spark_t in a pickup-edge ring
// window and return the spark angle IN A b-RELATIVE FRAME (b's rev == 0), or NaN
// if not yet bracketable (the trailing edge has not been captured, or the leading
// edge aged out). The b-relative frame keeps the interpolation in small angles
// regardless of how many revs the run has accumulated; the caller's to_btdc folds
// mod wheel, so the dropped b.rev*wheel offset does not change the result. `a` is
// b's rev or exactly one ahead, so a.intra + (a.rev-b.rev)*wheel is monotonic vs
// b.intra. Operates on the raw ring + running total so BOTH the stepped Reducer
// and the ramp RampReducer share the exact same math. Hot path. The three numeric
// params (pk_total, wheel_deg, spark_t) are distinct quantities; the proper guard is
// the deferred Ticks/Deg units layer, so for now the two callers pass named values.
// NOLINTNEXTLINE(bugprone-easily-swappable-parameters)
float __time_critical_func(bracket_pk)(const PkEdge* pk, std::uint32_t pk_total, float wheel_deg,
                                       std::uint64_t spark_t, std::uint32_t& rev_out) {
  const std::uint32_t valid = (pk_total < kPkRingCap) ? pk_total : kPkRingCap;
  if (valid < 2)
    return NAN;
  const std::uint32_t oldest = pk_total - valid; // absolute index of oldest kept
  for (std::uint32_t k = oldest; k + 1 < pk_total; ++k) {
    const PkEdge& b = pk[k % kPkRingCap];
    const PkEdge& a = pk[(k + 1) % kPkRingCap];
    if (b.t <= spark_t && spark_t < a.t) {
      core::EdgeRef before{b.t, b.intra};
      core::EdgeRef after{a.t, a.intra + float(a.rev - b.rev) * wheel_deg};
      rev_out = b.rev;
      return core::interp_angle(spark_t, before, after);
    }
  }
  return NAN;
}

// Stepped-Reducer adapter over bracket_pk (kept for call-site readability).
float __time_critical_func(bracket_angle)(const Reducer& rd, std::uint64_t spark_t,
                                          std::uint32_t& rev_out) {
  return bracket_pk(rd.pk_, rd.pk_total_, rd.wheel_deg_, spark_t, rev_out);
}

// Try to resolve every pending spark for one cylinder against the current pickup
// history; on success feed Welford + the median buffer and drop the spark.
// Sparks older than the retained pickup window (should not happen if the ring is
// sized right) are also dropped so pending never wedges. Hot path.
void __time_critical_func(resolve_pending)(Reducer& rd, std::uint8_t cyl) {
  std::size_t w = 0; // compaction write index for still-pending sparks
  const std::uint32_t valid = (rd.pk_total_ < kPkRingCap) ? rd.pk_total_ : kPkRingCap;
  const std::uint64_t oldest_t = (valid > 0) ? rd.pk_[(rd.pk_total_ - valid) % kPkRingCap].t : 0;
  for (std::size_t i = 0; i < rd.npend_[cyl]; ++i) {
    PendingSpark& s = rd.pend_[cyl][i];
    std::uint32_t rev = 0;
    float ang = bracket_angle(rd, s.t, rev);
    if (std::isnan(ang)) {
      // Not bracketable. If the spark predates the retained window it can never
      // be resolved -> drop it. Otherwise keep it for the next drain.
      if (valid >= 2 && s.t < oldest_t) {
        continue; // drop (compacted out)
      }
      rd.pend_[cyl][w++] = s;
      continue;
    }
    // Bracketed. Honor the settle window (skip the first settle_revs revs OF THIS
    // STEP -- rev is a continuous count across the whole sweep, so offset by the
    // step's entry rev), then accumulate BTDC + dwell up to the wanted sample count.
    if (rev >= rd.step_rev0_ + rd.settle_revs_ && rd.got_[cyl] < rd.want_) {
      const float tdc = rd.cfg_->tdc_ref_deg[cyl];
      const float btdc = core::to_btdc(ang, tdc, rd.wheel_deg_);
      rd.btdc_[cyl].add(btdc);
      if (rd.got_[cyl] < kMaxSamples)
        rd.btdc_buf_[cyl][rd.got_[cyl]] = btdc;
      if (s.has_dwell)
        rd.dwell_[cyl].add(float(s.dwell_ticks) / kCaptureCountsPerUs);
      ++rd.got_[cyl];
    }
    // Resolved -> dropped (compacted out) regardless of settle/want gating.
  }
  rd.npend_[cyl] = w;
}

// Reduce one tach reference edge (REFERENCE diagnostics only; never corrects
// BTDC). The DUT tach emits one RISING edge per crank rev aligned to tooth-0's
// rising edge, so:
//   * system latency = tach_rising - the emitted tooth-0 rising edge (a composite
//     input-path delay; clean-edge/bench value), accumulated into a Welford;
//   * sync-lock RPM comes from the interval between consecutive tach edges.
// Exercised only with a real ignitor connected: the tach<->tooth-0 pairing below assumes the most
// recent emitted tooth-0 rising edge (tracked from the pickup self-capture)
// precedes this tach edge within the same drain window. That holds because
// drain() returns the pickup slot before the tach slot, so tooth-0 for this rev
// is already recorded. On the bench no tach edge ever arrives, so this path is
// simply never exercised until a real ignitor is present. Hot path -> RAM.
void __time_critical_func(process_tach_edge)(Reducer& rd, std::uint64_t ticks, bool rising) {
  if (!rising) {
    return; // only the rising reference edge (once per rev) is meaningful
  }
  // Sync-lock RPM (rising-to-rising interval) + input-path latency vs the emitted
  // tooth-0 rising edge (both skew-corrected). Accumulated per step; begin_step
  // resets the accumulator so these track the current rpm, not the whole sweep.
  rd.tach_.on_rising(ticks, rd.have_tooth0_, rd.last_tooth0_t_);
}

// Process one drained batch of CaptureEvents: append pickup edges to the history,
// pair + queue ignition sparks, then resolve pending sparks. Because drain()
// returns each channel's events contiguously and time-ordered (pickup slot first,
// then ign slots), the pickup history is fully up to date before any spark in the
// same batch is examined. Hot path -> RAM-resident.
void __time_critical_func(process_batch)(Reducer& rd, const hal::CaptureEvent* ev, std::size_t n) {
  for (std::size_t i = 0; i < n; ++i) {
    const hal::CaptureEvent& e = ev[i];
    // Capture-clock skew correction (see Reducer): add back this channel's
    // accumulated counter-pause so pickup and ignition timestamps live in ONE
    // pause-free timebase -- otherwise a spark (ignition channel) compared to a
    // tooth (pickup channel) drifts ATDC over a run. Shared with the ramp path via
    // core::skew_corrected_ticks (adds cfg::kCounterPauseCountsPerEdge per handled edge).
    const int ci = skew_ch_idx(e.ch);
    std::uint64_t ct = e.ticks;
    if (ci >= 0) {
      ct = core::skew_corrected_ticks(e.ticks, rd.ch_edges_[ci]);
      ++rd.ch_edges_[ci];
    }
    if (e.ch == kPickupChId) {
      // SYNC-GAP alignment (self-healing): the 170-deg sync gap (tooth-3 trailing
      // -> tooth-0 leading) is the largest inter-edge gap; crossing it re-aligns
      // intra_idx_ to 0 and bumps sync_rev_, re-deriving tooth-0 every revolution.
      const bool is_sync = rd.have_last_pk_ && rd.sync_thresh_ticks_ &&
                           (ct - rd.last_pk_t_) >= rd.sync_thresh_ticks_;
      rd.last_pk_t_ = ct;
      rd.have_last_pk_ = true;
      if (is_sync) {
        rd.intra_idx_ = 0;
        if (rd.synced_)
          ++rd.sync_rev_; // a full rev completed since the previous sync
        rd.synced_ = true;
      } else if (rd.synced_) {
        ++rd.intra_idx_;
      }
      PkEdge& slot = rd.pk_[rd.pk_total_ % kPkRingCap];
      slot.t = ct;
      slot.rev = rd.sync_rev_;
      if (rd.synced_ && rd.intra_idx_ < rd.edges_per_rev_) {
        slot.intra = rd.intra_angle_[rd.intra_idx_]; // small; rev kept separately
        // Tooth-0's RISING (leading) edge is intra index 0 -> tach latency ref.
        if (rd.intra_idx_ == 0 && e.rising) {
          rd.last_tooth0_t_ = ct;
          rd.have_tooth0_ = true;
        }
      } else {
        slot.intra = NAN; // not yet synced, or a glitch overran the rev -> unbracketable
      }
      ++rd.pk_total_;
      continue;
    }
    // Tach reference-diagnostic channel (REFERENCE only; never corrects BTDC).
    if (e.ch == kTachChannel) {
      process_tach_edge(rd, ct, e.rising);
      continue;
    }
    // Ignition channel: e.ch is the cylinder index.
    if (e.ch >= rd.cyl_count_ || e.ch >= core::kMaxCylinders)
      continue;
    // Predictive dwell: a FALLING edge (charge start) may legitimately
    // precede its tooth; DwellPairer records fall->rise, so falling edges are
    // never anomalous. Only the RISING edge (spark) is bracketed against pickup.
    core::DwellResult dr = rd.pairer_.on_edge(e.ch, e.rising, ct);
    if (e.rising) {
      if (rd.npend_[e.ch] < kMaxPending) {
        PendingSpark& s = rd.pend_[e.ch][rd.npend_[e.ch]++];
        s.t = ct;
        s.has_dwell = dr.has_dwell;
        s.dwell_ticks = dr.dwell_ticks;
      }
      // else: pending queue saturated (should not happen at realistic edge rates);
      // the spark is simply not counted this pass.
    }
  }
  for (std::uint8_t c = 0; c < rd.cyl_count_ && c < core::kMaxCylinders; ++c)
    resolve_pending(rd, c);
}

// True once every active cylinder has gathered its wanted sample count.
bool step_complete(const Reducer& rd) {
  for (std::uint8_t c = 0; c < rd.cyl_count_ && c < core::kMaxCylinders; ++c) {
    if (rd.got_[c] < rd.want_)
      return false;
  }
  return true;
}
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

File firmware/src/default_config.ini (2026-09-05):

; SRV250 default configuration. Edit on the mounted USB drive; need reboot.

; Run mode: STEPPED | RAMP_UP | RAMP_DOWN | HOLD (picks the block used below).
RUN_MODE            = STEPPED

; STEPPED sweep: start->end inclusive by step. Also bounds the RAMP modes.
SWEEP_START_RPM     = 100
SWEEP_END_RPM       = 10000
SWEEP_STEP_RPM      = 100
; Revs to settle at each step before sampling, and samples reduced per step.
SWEEP_SETTLE_REVS   = 8
SWEEP_SAMPLES       = 16

; HOLD mode: constant RPM held indefinitely (optional; firmware default if omitted).
HOLD_RPM            = 3000

; RAMP modes: slew rate across the sweep span, in rpm per second.
RAMP_UP_RPM_PER_S   = 500
RAMP_DOWN_RPM_PER_S = 500

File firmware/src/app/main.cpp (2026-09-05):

// Core-0 integration super-loop.
//
// Core 0 owns USB (custom CDC+MSC composite exposing the flash FAT), the FatFs
// volume, the FSM + LED, and BOOTSEL. Core 1 owns the
// deterministic capture+reduce pipeline. The ONLY data that crosses core1->core0
// is reduced result rows (core::SteppedRow for stepped runs, core::RampRow for
// ramp/hold) over the SPSC rings in g_ic; a handful of atomics coordinate run
// start/stop and the flash-write window.
//
// Two hard interlocks are enforced here:
//   * WRITER LOCK: while a run holds the FS, the MSC medium is reported read-only
//     (hal::msc_set_readonly(true)) so the host PC cannot mutate the volume out
//     from under the firmware. It is released back to read-write once the FS is
//     free again (run finished + results flushed, or run aborted).
//   * FLASH-WRITE-IDLE: core0 NEVER writes flash while core1 is actively
//     capturing (g_ic.capture_idle == false). Result rows are buffered in SRAM
//     during the run and flushed only once capture is idle at end-of-run. This
//     avoids XIP stalls colliding with the deterministic capture path.
//
// The full runtime behavior (multicore + SPSC + MSC coexistence, BOOTSEL start,
// CONFIG.INI flow) integrates hardware-only paths and is exercised on silicon,
// not by the host unit tests.

#include "app/core1_main.hpp"
#include "core/config.hpp"
#include "core/csv.hpp"
#include "core/fileio.hpp"
#include "core/fsm.hpp"
#include "core/hold_ring.hpp"
#include "hal/flashfs.hpp"
#include "hal/flashfs_backend.hpp"
#include "hal/gpio.hpp"
#include "hal/usb_msc.hpp"
#include "hardware/sync.h"
#include "pico/multicore.h"
#include "pico/stdlib.h"
#include "tusb.h"
#include "version.hpp" // generated (build dir): build::kVersion from git describe

#include <array>
#include <atomic>
#include <cstddef>
#include <cstdint>
#include <cstdio>
#include <string_view>

namespace {

std::uint32_t now_ms() { return to_ms_since_boot(get_absolute_time()); }

// ---- LED pattern renderer (core0-side) --------------------------------------
// core::led_for() maps a State to a LedPattern; here we turn that pattern into a
// concrete on/off level for the current millisecond. Purely time-based (a modulo
// of now_ms), no sleeps -- the caller sets the LED once per loop tick so nothing
// starves tud_task().
bool led_level(core::LedPattern p, std::uint32_t t) {
  switch (p) {
  case core::LedPattern::Off:
    return false;
  case core::LedPattern::Blink1Hz:
    return (t % 1000u) < 500u; // 1 Hz, 50% duty
  case core::LedPattern::Blink10Hz:
    return (t % 100u) < 50u; // 10 Hz, 50% duty
  case core::LedPattern::Heartbeat: {
    // Two short pulses near the start of a 1 s cycle, then quiet.
    const std::uint32_t ph = t % 1000u;
    return ph < 80u || (ph >= 160u && ph < 240u);
  }
  case core::LedPattern::DoubleBlink: {
    // Two ~120 ms blinks per 1 s (flush indicator).
    const std::uint32_t ph = t % 1000u;
    return ph < 120u || (ph >= 240u && ph < 360u);
  }
  case core::LedPattern::SolidBriefly:
    return true; // Done state is momentary; render solid on.
  case core::LedPattern::ErrorTriple: {
    // Three quick blinks then a pause, over a 1.6 s cycle.
    const std::uint32_t ph = t % 1600u;
    return ph < 120u || (ph >= 240u && ph < 360u) || (ph >= 480u && ph < 600u);
  }
  }
  return false;
}

// In-SRAM buffer for one sweep's reduced rows. The default full-range sweep is
// ~200 rows (100 steps x 2 cylinders), so 256 leaves only modest headroom; rows
// beyond the cap are dropped rather than overrun (comment at the drain site).
constexpr std::size_t kMaxRows = 256;

// Write a leading "# firmware: <git-describe>" comment into the currently-open
// output file, so every result CSV records which firmware produced it (data
// provenance). '#' is already the comment convention in these files (ramp
// TRUNCATED marker); readers skip it with comment='#'.
void write_version_stamp(hal::FlashFsBackend& be) {
  char vs[64];
  const int n = std::snprintf(vs, sizeof vs, "# firmware: %s\n", build::kVersion);
  if (n > 0)
    be.append(std::string_view(vs, static_cast<std::size_t>(n)));
}

// Perform the end-of-run flush to a fresh MAP_xxx.CSV. PRECONDITION: caller has
// verified g_ic.capture_idle == true (flash-write-idle interlock). Writes the CSV
// header then every buffered row. Returns after releasing the writer lock so the
// host is read-write again while the FS is idle.
void flush_results(hal::FlashFsBackend& be, const core::SteppedRow* rows, std::size_t n) {
  char name[13];
  // Scan the live FS for the lowest free MAP_xxx (never overwrite an existing file;
  // a RAM counter would reset to 1 on reboot and clobber last session's map).
  hal::fs_next_free_name(name, sizeof name, "MAP_%03u.CSV");
  be.set_output_file(name);
  be.open_output(); // stream the flush (append falls back to per-call if this fails)
  write_version_stamp(be);

  char hdr[192]; // stepped header is ~140 chars now (tach diagnostic columns)
  const std::size_t hn = core::csv_stepped_header(hdr, sizeof hdr);
  if (hn > 0)
    be.append(std::string_view(hdr, hn));
  for (std::size_t i = 0; i < n; ++i)
    core::write_stepped_row(be, rows[i]);
  be.close_output(); // sync + close the streamed file

  // FS is free again -> re-enable host writes (writer lock only while a
  // run holds the FS; RW when idle so the PC can manage files between runs).
  hal::msc_set_readonly(false);
}

// Drain the ramp per-spark rows core 1 produces into the SRAM buffer. Ramp is a
// higher-rate stream than stepped, so this MUST run every loop tick. Overflow
// beyond kMaxRampRows stops storing and raises the truncation flag, but keeps
// popping so core 1's producer ring never wedges (dropped rows are acceptable --
// the raw trajectory tolerates gaps; the flag makes the truncation non-silent).
void drain_ramp(std::array<core::RampRow, cfg::kMaxRampRows>& buf, std::size_t& n) {
  core::RampRow row;
  while (app::g_ic.ramp_results.pop(row)) {
    if (n < cfg::kMaxRampRows)
      buf[n++] = row;
    else
      app::g_ic.ramp_truncated.store(true, std::memory_order_relaxed);
  }
}
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

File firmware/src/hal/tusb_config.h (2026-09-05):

#ifndef PROBER_HAL_TUSB_CONFIG_H
#define PROBER_HAL_TUSB_CONFIG_H

// TinyUSB device configuration for the 4dn Timing Probe composite (CDC + MSC).
// Compiled into any target that links `prober_usb` (usb_descriptors.c, usb_msc.cpp)
// and the pico-sdk TinyUSB sources. NOTE: this MUST NOT be combined with
// pico_enable_stdio_usb in the same executable -- that shim ships its own
// tusb_config.h + descriptors and would collide. hil_selftest keeps stdio_usb;
// hil_msc uses this.

#ifdef __cplusplus
extern "C" {
#endif

// CFG_TUSB_MCU and CFG_TUSB_OS are supplied by the pico-sdk TinyUSB CMake
// (tinyusb_common_base defines CFG_TUSB_MCU=OPT_MCU_RP2040, CFG_TUSB_OS=OPT_OS_PICO
// via -D). We restate the expected values behind guards so this header is
// self-describing without redefining the command-line macros.
#ifndef CFG_TUSB_MCU
#define CFG_TUSB_MCU OPT_MCU_RP2040
#endif

#ifndef CFG_TUSB_OS
#define CFG_TUSB_OS OPT_OS_PICO
#endif

#ifndef CFG_TUSB_DEBUG
#define CFG_TUSB_DEBUG 0
#endif

// RHPort 0 device, default full speed on the RP2040 on-chip PHY.
#ifndef BOARD_TUD_RHPORT
#define BOARD_TUD_RHPORT 0
#endif

#ifndef BOARD_TUD_MAX_SPEED
#define BOARD_TUD_MAX_SPEED OPT_MODE_DEFAULT_SPEED
#endif

// Enable device stack.
#define CFG_TUD_ENABLED 1
#define CFG_TUD_MAX_SPEED BOARD_TUD_MAX_SPEED

#ifndef CFG_TUSB_MEM_SECTION
#define CFG_TUSB_MEM_SECTION
#endif

#ifndef CFG_TUSB_MEM_ALIGN
#define CFG_TUSB_MEM_ALIGN __attribute__((aligned(4)))
#endif

#ifndef CFG_TUD_ENDPOINT0_SIZE
#define CFG_TUD_ENDPOINT0_SIZE 64
#endif

//------------- CLASS -------------//
#define CFG_TUD_CDC 1
#define CFG_TUD_MSC 1
#define CFG_TUD_HID 0
#define CFG_TUD_MIDI 0
#define CFG_TUD_VENDOR 0

// CDC FIFO size of TX and RX (full speed).
#define CFG_TUD_CDC_RX_BUFSIZE 64
#define CFG_TUD_CDC_TX_BUFSIZE 64

// CDC endpoint transfer buffer size.
#define CFG_TUD_CDC_EP_BUFSIZE 64

// MSC endpoint buffer: one 512 B logical sector per transfer, matching the flash
// FAT volume's logical sector size (see hal/flash_msc.hpp / diskio_flash.cpp).
#define CFG_TUD_MSC_EP_BUFSIZE 512

#ifdef __cplusplus
}
#endif

#endif /* PROBER_HAL_TUSB_CONFIG_H */

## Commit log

2026-09-05 Add run result CSV
    [MAP_001.CSV]
2026-09-05 Fix schematic color
    [4dn-firing-timing-probe.kicad_sch]
